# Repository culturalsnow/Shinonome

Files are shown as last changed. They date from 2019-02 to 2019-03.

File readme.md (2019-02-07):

Shinonome
===

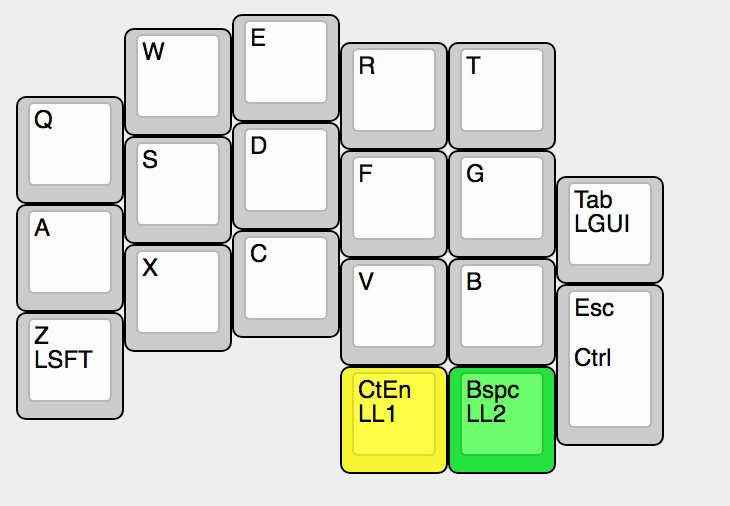
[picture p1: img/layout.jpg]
Shinonome


38-key columnar stagger keyboard inspired by the Mitosis, Chimera Ergo, Corne and Comet46.

Keyboard Maintainer: [Cultural Snow](https://github.com/culturalsnow/) / [@SA_EndlessGame](https://twitter.com/SA_EndlessGame)  
Hardware Supported: Shinonome PCB  
Hardware Availability: (https://twitter.com/SA_EndlessGame)

Make example for this keyboard (after setting up your build environment):

    make shinonome:default

See the [build environment setup](https://docs.qmk.fm/#/getting_started_build_tools) and the [make instructions](https://docs.qmk.fm/#/getting_started_make_guide) for more information. Brand new to QMK? Start with our [Complete Newbs Guide](https://docs.qmk.fm/#/newbs).

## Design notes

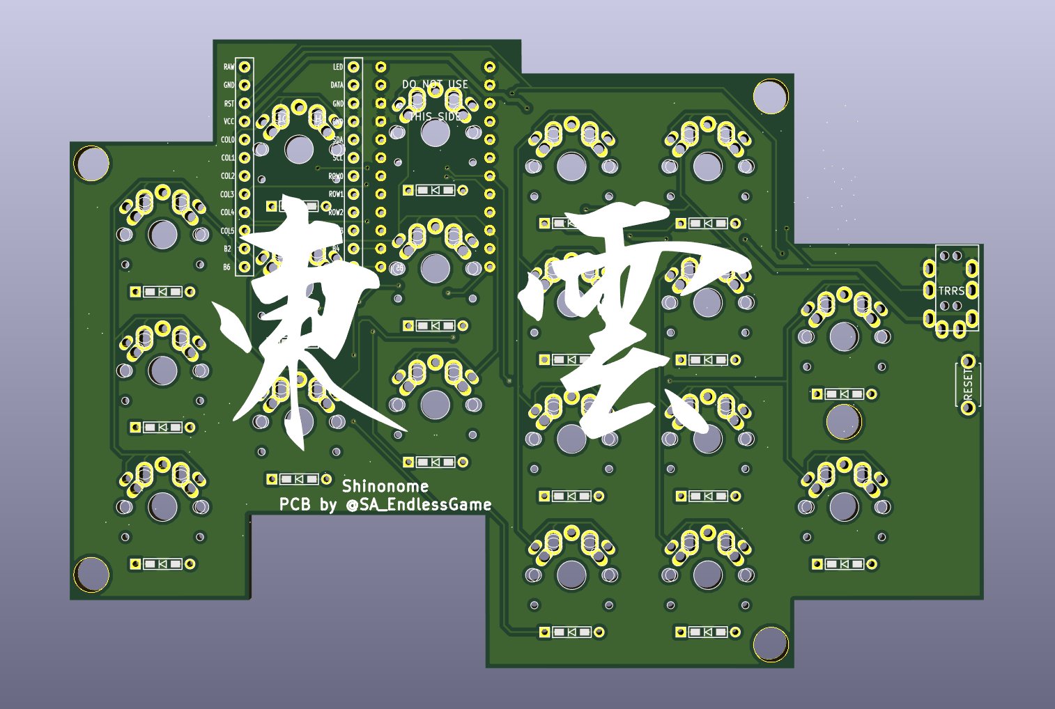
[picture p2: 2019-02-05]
img/PCB.jpg

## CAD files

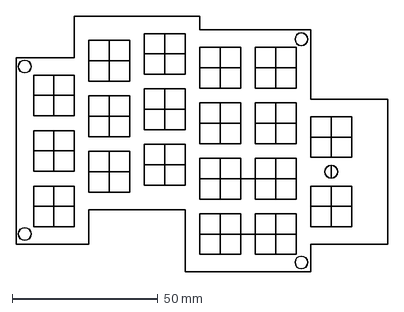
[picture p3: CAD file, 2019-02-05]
PCB/Shinonome.dxf
127.7 x 87.9 mm

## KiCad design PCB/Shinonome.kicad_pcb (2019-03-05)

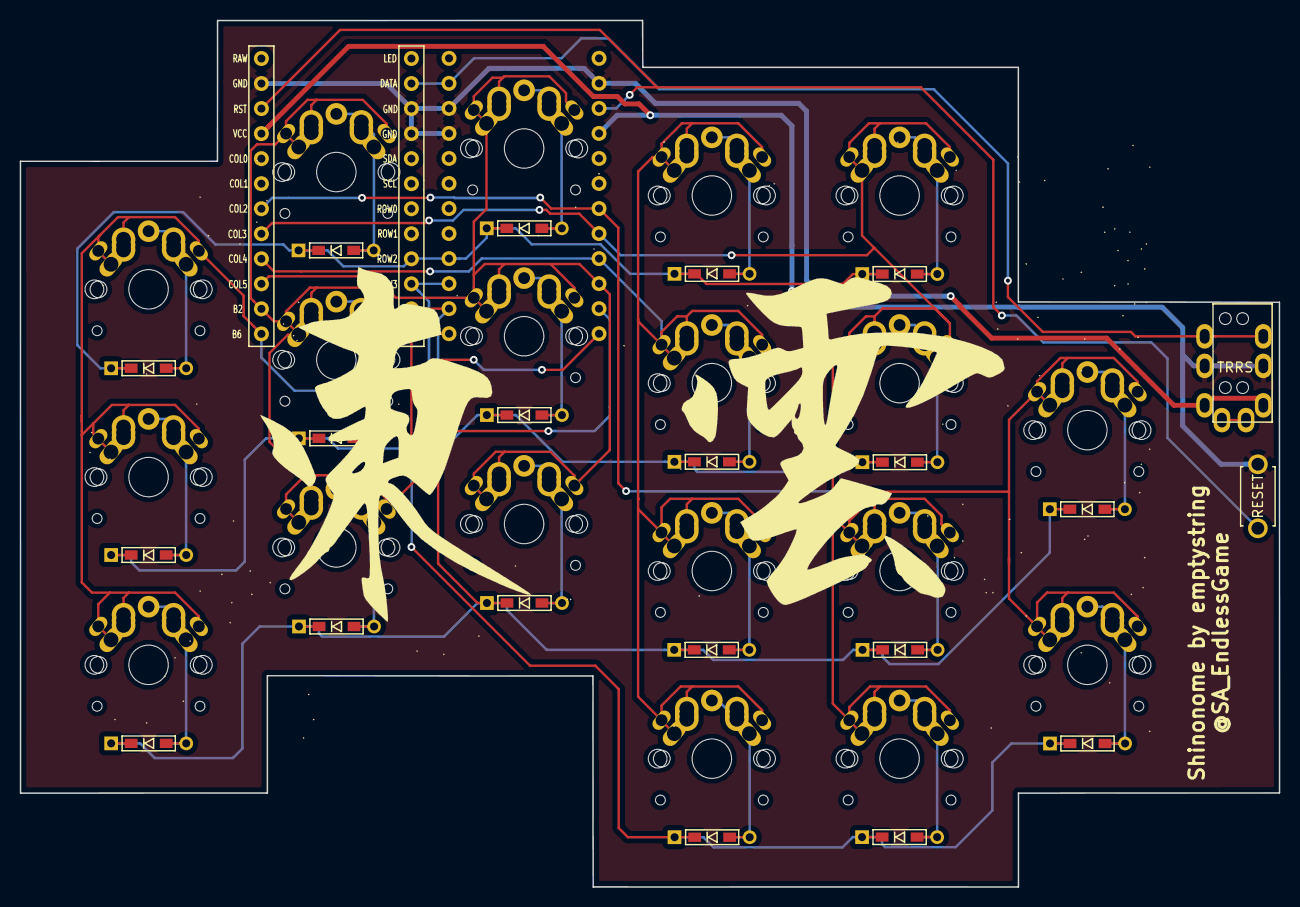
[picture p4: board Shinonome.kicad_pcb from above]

Board: 2 copper layers, 127.7 x 87.9 mm, 42 parts (1 on the bottom side), 33 nets.

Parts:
D1, D2, D3, D4, D5, D6, D7, D8, D9, D10, D11, D12, D13, D14, D15, D16, D17, D18, D19: D; D3_TH_SMD
J1: MJ-4PP-9
SW1, SW2, SW3, SW4, SW5, SW6, SW7, SW8, SW9, SW10, SW11, SW12, SW13, SW14, SW15, SW16, SW17, SW18, SW19: SW_PUSH; MX_ALPS_PG1350_noLed
SW20: reset; ResetSW
U1, U2: ProMicro; ProMicro_v2_Backside

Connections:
GND: J1.C, SW20.2, U1.3, U1.4, U1.23, U2.3, U2.4, U2.23
unnamed: D1.2, SW1.2
unnamed: D2.2, SW2.2
unnamed: D3.2, SW3.2
unnamed: D4.2, SW4.2
unnamed: D5.2, SW5.2
unnamed: D6.2, SW6.2
unnamed: D7.2, SW7.2
unnamed: D8.2, SW8.2
unnamed: D9.2, SW9.2
unnamed: D10.2, SW10.2
unnamed: D11.2, SW11.2
unnamed: D12.2, SW12.2
unnamed: D13.2, SW13.2
unnamed: D14.2, SW14.2
unnamed: D15.2, SW15.2
unnamed: D16.2, SW16.2
unnamed: D17.2, SW17.2
unnamed: D18.2, SW18.2
unnamed: D19.2, SW19.2
VCC: J1.D, U1.21, U2.21
col0: SW1.1, SW2.1, SW3.1, U1.13, U2.13
col1: SW4.1, SW5.1, SW6.1, U1.14, U2.14
col2: SW7.1, SW8.1, SW9.1, U1.15, U2.15
col3: SW10.1, SW11.1, SW12.1, SW13.1, U1.16, U2.16
col4: SW14.1, SW15.1, SW16.1, SW17.1, U1.17, U2.17
col5: SW18.1, SW19.1, U1.18, U2.18
data: J1.B, U1.2, U2.2
reset: SW20.1, U1.22, U2.22
row0: D1.1, D4.1, D7.1, D10.1, D14.1, U1.9, U2.9
row1: D2.1, D5.1, D8.1, D11.1, D15.1, U1.10, U2.10
row2: D3.1, D6.1, D9.1, D12.1, D16.1, D18.1, U1.11, U2.11
row3: D13.1, D17.1, D19.1, U1.12, U2.12

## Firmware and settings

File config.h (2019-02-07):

/*
Copyright 2012 Jun Wako <wakojun@gmail.com>
Copyright 2015 Jack Humbert
Copyright 2019 Bernard Shih <twitter: @SA_EndlessGame>

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
You should have received a copy of the GNU General Public License
along with this program.  If not, see <http://www.gnu.org/licenses/>.
*/

#pragma once

#include "config_common.h"
#include <serial_config.h>

/* USB Device descriptor parameter
   VID & PID are lisenced from microchip sublisence program, Don't use other project! */
#define VENDOR_ID       0x0076
#define PRODUCT_ID      0xFF38
#define DEVICE_VER      0x0001
#define MANUFACTURER    EMPTYSTRING
#define PRODUCT         Shinonome
#define DESCRIPTION     38-key split keyboard

#define RETRO_TAPPING
#define TAPPING_TERM 300

#define CATERINA_BOOTLOADER

#define USE_SERIAL

/* Select hand configuration */
#define MASTER_LEFT
// #define MASTER_RIGHT
// #define EE_HANDS

/* key matrix size */
// Rows are doubled-up
#define MATRIX_ROWS 8
#define MATRIX_ROW_PINS { D7, E6, B4, B5 }

// wiring of each half
#define MATRIX_COLS 6
#define MATRIX_COL_PINS { B6, B2, B3, B1, F7, F6 }

/* define if matrix has ghost */
//#define MATRIX_HAS_GHOST

/* number of backlight levels */
// #define BACKLIGHT_LEVELS 3

/* Set 0 if debouncing isn't needed */
#define DEBOUNCING_DELAY 5

/* Mechanical locking support. Use KC_LCAP, KC_LNUM or KC_LSCR instead in keymap */
#define LOCKING_SUPPORT_ENABLE
/* Locking resynchronize hack */
#define LOCKING_RESYNC_ENABLE

/* ws2812 RGB LED
#define RGB_DI_PIN B6

#define RGBLED_NUM 7

#ifndef IOS_DEVICE_ENABLE
  #if RGBLED_NUM <= 7
    #define RGBLIGHT_LIMIT_VAL 255
    #define RGBLIGHT_VAL_STEP 17
  #endif
#else
  #define RGBLIGHT_LIMIT_VAL 90
  #define RGBLIGHT_VAL_STEP 4
#endif

#define RGBLIGHT_HUE_STEP 10
#define RGBLIGHT_SAT_STEP 17

#if defined(RGBLIGHT_ENABLE) && !defined(IOS_DEVICE_ENABLE)
  #define USB_MAX_POWER_CONSUMPTION 500
#else
  // fix iPhone and iPad power adapter issue
  // iOS device need lessthan 100
  #define USB_MAX_POWER_CONSUMPTION 100
#endif
*/

/*
 * Feature disable options
 *  These options are also useful to firmware size reduction.
 */

/* disable debug print */
// #define NO_DEBUG

/* disable print */
// #define NO_PRINT

/* disable action features */
//#define NO_ACTION_LAYER
//#define NO_ACTION_TAPPING
//#define NO_ACTION_ONESHOT
//#define NO_ACTION_MACRO
//#define NO_ACTION_FUNCTION

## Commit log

2019-02-02 20190202 first commit
    [Shinonome.kicad_pcb, Shinonome.sch]
2019-02-02 changed directory hierarchy
    [Shinonome.kicad_pcb, Shinonome.sch]
2019-02-02 added dxf file
    [Shinonome.dxf]
2019-02-04 new dxf file
    [Shinonome.dxf]
2019-02-05 first pass pcb complete
    [Shinonome.dxf, Shinonome.kicad_pcb, Shinonome.sch]
2019-02-13 added logos and removed confusing warning from PM footprint
    [Shinonome.kicad_pcb]
2019-02-18 gerber created
    [Shinonome-B.Cu.gbr, Shinonome-B.Mask.gbr, Shinonome-B.SilkS.gbr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]
2019-03-05 fixed trrs jack incorrect pins
    [Shinonome-B.Cu.gbr, Shinonome-B.Mask.gbr, Shinonome-B.SilkS.gbr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]
2019-03-05 added logos and regenerated gerber
    [Shinonome-B.Cu.gbr, Shinonome-B.Mask.gbr, Shinonome-B.SilkS.gbr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]

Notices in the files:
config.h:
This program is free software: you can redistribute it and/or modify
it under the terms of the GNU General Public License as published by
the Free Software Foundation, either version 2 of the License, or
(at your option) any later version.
